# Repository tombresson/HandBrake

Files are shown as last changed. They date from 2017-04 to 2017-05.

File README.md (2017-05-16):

# USB Handbrake 

## Abstract

This goal of this project was to use a commercially available handbrake and convert it into a USB controller that could output an analog axis value, a joystick button (at a configurable threshold) or a keypress (at a configurable threshold).  The parts had to be readily available, but 3D printed parts could be utilized. The cost also had to be low, as this was a project for for a DIY piece of Sim Racing kit. Commercially available hardware already exists for a high (but not exuberant) price.

## Features

The USB Handbrake has the following features:

* Outputs a Joystick Analog (z-axis), Joystick Digital (button 1) or Keyboard key to provide universal support to any PC game
* Allows configuration of the device through the serial interface to configure:
  * Key that is pressed when in "Keyboard" mode
  * Threshold for the digital outputs
  * RGB LED Brightness
  * Deadzone for the "Pulled" and "Released" positions
* Allows for calibration of the device to set the full "Released" and "Pulled" sensor values
* Returns to the last mode after on power-up (Joystick Analog, Joystick Digital, or Keyboard)

## Hardware

### Mechanical

#### Bill of Materials

1 - Generic Generic Hydraulic Handbrake 
4 - M8 x 20mm x 1.25 (Box mounting and Rear O-ring attach point)
2 - M8 x 30mm x 1.25 (Front O-Ring attach point)
1 - M8 x 80mm x 1.25 ("Piston")
1 - 1/2" x 1/16" N52 Neodymium Magnet
1 - Spring (?)
2 - O-Rings (1-1/8 ID x 1-3/8 OD x 1/8 Diameter)
4 - Nylon Spacers
4 - M8 Washers
1 - 3D Printed Sensor Enclosure
1 - 3D Printed Bolt Guide Plate

#### Assembly

### Electronics

#### Bill of Materials

1 - Arduino platform (Teensy 3.1)
1 - Push Button
1 - RGB LED
1 - SOT-23 Breakout Board
1 - DRV5053RA (SOT-23 form factor)

#### Schematic

## Software

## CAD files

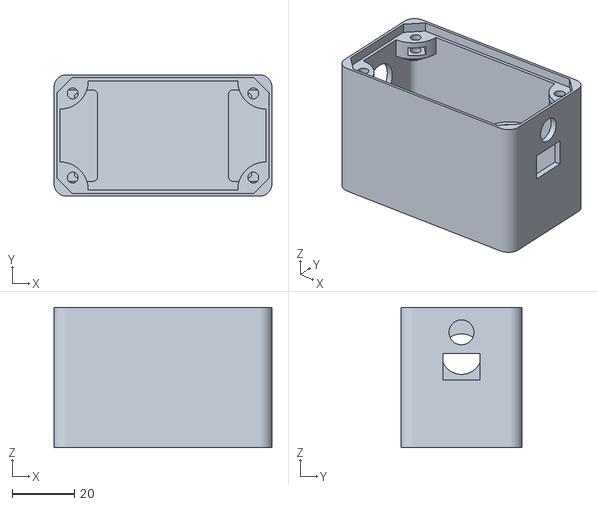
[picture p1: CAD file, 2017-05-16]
models/STLs/Electronics_Enclosure.stl
70.0 x 39.0 x 45.0

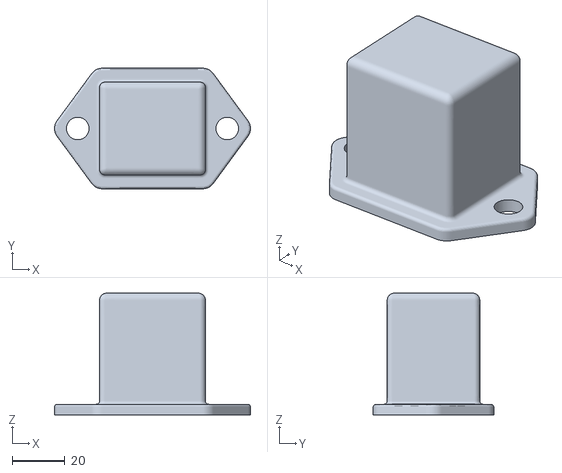
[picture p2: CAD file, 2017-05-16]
models/STLs/Sensor_Enclosure.stl
74.1 x 45.6 x 46.0

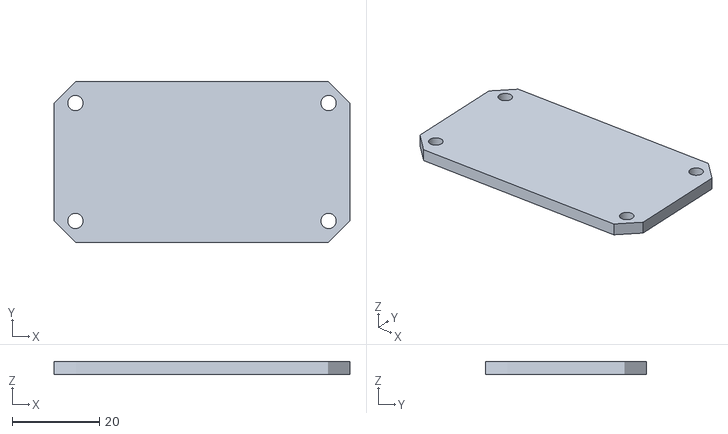
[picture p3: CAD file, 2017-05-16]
models/STLs/Electronics_Enclosure_Top.stl
67.8 x 36.8 x 3.00

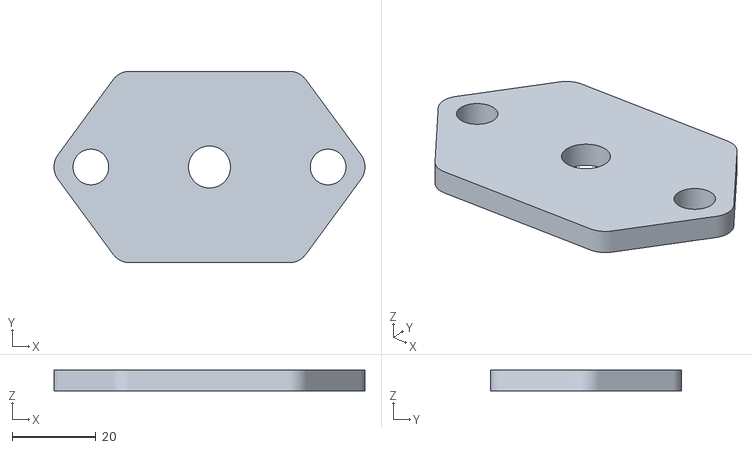
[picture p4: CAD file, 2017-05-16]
models/STLs/Bolt_Guide_Plate.stl
74.1 x 45.6 x 5.00

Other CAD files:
models/Fusion360/Bolt_Guide_Plate.f3d
models/Fusion360/Electronics_Enclosure.f3d
models/Fusion360/Electronics_Enclosure_Top.f3d
models/Fusion360/Sensor_Enclosure.f3d

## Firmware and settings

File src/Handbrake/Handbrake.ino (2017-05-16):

/* Complete USB Joystick Example
   Teensy becomes a USB joystick with 16 or 32 buttons and 6 axis input

   You must select Joystick from the "Tools > USB Type" menu

   Pushbuttons should be connected between the digital pins and ground.
   Potentiometers should be connected to analog inputs 0 to 5.

   This example code is in the public domain.
*/

/************************************* INCLUDES *************************************/

#include <stdint.h>

#include <EEPROMex.h>
#include <EEPROMVar.h>

#include "utilities.h"
#include "RGBTools.h"

/************************************** MACROS **************************************/
// Turns Debug on and off
#define HANDBRAKE_DEBUG 0

// Turn on verbose debugging
#define HANDBRAKE_DEBUG_VERBOSE 0

// EEPROM abstracted address position
#define HANDBRAKE_EEPROM_ADDR 0U

// Buffer for serial data
#define HANDBRAKE_SERIAL_BUFF_SIZE 64U

#define HANDBRAKE_ADC_MAX 1023U

#define HANDBRAKE_JOY_AXIS_MAX 1023U

// Button to send for the joystick button threshold
#define HANDBRAKE_JOY_BUTTON 1U

// Duration of button hold to enter calibration mode
#define HANDBRAKE_BUTTON_HOLD_TIME_MS 5000U

// Serial Config Parsing Timeout
#define HANDBRAKE_SERIAL_TIMEOUT 5000

// Resting value for joystick position
#define JOYSTICK_RESTING_POS 512U

#define HANDBRAKE_POSITION_MAX 100.0F
#define HANDBRAKE_POSITION_MIN 0.0F

// The hysteresis (in percentage) that in used for the button/key press
#define HANDBRAKE_THRESH_HYSTERESIS 5U

#define HANDBRAKE_LED_DEFAULT_BRIGHTNESS 100

#define HANDBRAKE_DEFAULT_BUTTON_THRESH 50U

// The percentage of the total range that the calibration is narrowed by
// This will ensure that the analog axis travels from 0 to 100%
// Upper deadband is for fully pulled back position, lower deadband is for released position
#define HANDBRAKE_UPPER_DEADZONE_BAND 5U
#define HANDBRAKE_LOWER_DEADZONE_BAND 10U

// GPIO pin for the mode select button
#define HANDBRAKE_MODE_SELECT_BUTTON 12

// Handbrake Modes
#define HANDBRAKE_UNKNOWN_MODE 0x00
#define HANDBRAKE_KEYBOARD_MODE 0x01
#define HANDBRAKE_BUTTON_MODE 0x02
#define HANDBRAKE_ANALOG_MODE 0x03
#define HANDBRAKE_CALIBRATE_MODE 0x04
#define HANDBRAKE_CONFIG_MODE 0x05

#define HANDBRAKE_NUM_MODES 0x06

/*********************************** DEFINITIONS ************************************/

const char *k_mode_names[HANDBRAKE_NUM_MODES] =
    {
        "UNKNOWN", //< Mode 0 is undefined
        "KEYBOARD",
        "BUTTON",
        "ANALOG",
        "CALIBRATION",
        "CONFIG"};

typedef struct
{
  uint32_t config_mode;
  uint32_t led_color;
  uint32_t blink_interval;
  uint8_t duty_cycle;
} configMode_t;

/// @brief Definition of the revision number for checking to see if EEPROM data is compatable
/// Anytime the EEPROM data structure is changed, this needs to be updated
#define REVISION_NUM 102

typedef struct
{
  uint32_t rev_number;            //< Revision number of the eeprom data struct
  uint32_t data_size;             //< Size of the data structure
  uint32_t cal_max;               //< Raw ADC value that represents 100%
  uint32_t cal_min;               //< Raw ADC value that represents 0%
  uint32_t button_threshold;      //< Threshold (0%-100%) where the button is activated/deactivated
  uint16_t conf_key_code;         //< Configured key for the Keyboard Mode
  uint8_t mode;                   //< Current mode the device is in
  uint8_t led_brightness;         //< The LED brightness for the LED indicator
  uint8_t upper_deadband_percent; //< The upper (pulled) deadband percentage
  uint8_t lower_deadband_percent; //< The lower (released) deadband percentage
} eepromData_t;

/******************************* FUNCTION DEFINITIONS *******************************/

static void handbrakeInitialConditions(void);
static void handbrakeProcessSerial(void);
static void handbrakeServiceModeButton(void);
static uint32_t handbrakeGetModeIdx(void);
static void handbrakeUpdateSettings(eepromData_t *p_data);
static void handbrakeLoadSettings(eepromData_t *p_data);
static bool handbrakeValidateSettings(const eepromData_t *p_data);
static uint32_t handbrakeProcessSerialLong(uint32_t upper_bound, uint32_t lower_bound, uint32_t original_value);
static uint16_t handbrakeProcessSerialFindKey(uint16_t original_key);
static uint32_t handbrakeFindKeyIdx(uint16_t key_code);

/************************************* GLOBALS **************************************/

// Array of modes which can be cycled through by momentary press on the button
static configMode_t modes[] =
    {
        {HANDBRAKE_KEYBOARD_MODE, Color::GREEN, 0, 0},
        {HANDBRAKE_BUTTON_MODE, Color::BLUE, 0, 0},
        {HANDBRAKE_ANALOG_MODE, Color::RED, 0, 0},
        {HANDBRAKE_CONFIG_MODE, Color::PURPLE, 1000, 90}};

// Configure the number of buttons.  Be careful not
// to use a pin for both a digital button and analog
// axis.  The pullup resistor will interfere with
// the analog voltage.
static const int numButtons = 8; // 16 for Teensy, 32 for Teensy++

static const char *gp_key_strings[] =
    {"A", "B", "C", "D", "E", "F", "G", "H", "I", "J",
     "K", "L", "M", "N", "O", "P", "Q", "R", "S", "T",
     "U", "V", "W", "X", "Y", "Z", "1", "2", "3", "4",
     "5", "6", "7", "8", "9", "0", "ENTER", "ESC", "BACKSPACE",
     "TAB", "SPACE", "MINUS", "EQUAL", "LEFT_BRACE", "RIGHT_BRACE",
     "BACKSLASH", "NON_US_NUM", "SEMICOLON", "QUOTE", "TILDE", "COMMA",
     "PERIOD", "SLASH", "CAPS_LOCK", "F1", "F2", "F3", "F4", "F5",
     "F6", "F7", "F8", "F9", "F10", "F11", "F12", "PRINTSCREEN",
     "SCROLL_LOCK", "PAUSE", "INSERT", "HOME", "PAGE_UP", "DELETE",
     "END", "PAGE_DOWN", "RIGHT", "LEFT", "DOWN", "UP", "NUM_LOCK",
     "KEYPAD_SLASH", "KEYPAD_ASTERIX", "KEYPAD_MINUS", "KEYPAD_PLUS", "KEYPAD_ENTER", "KEYPAD_1",
     "KEYPAD_2", "KEYPAD_3", "KEYPAD_4", "KEYPAD_5", "KEYPAD_6", "KEYPAD_7", "KEYPAD_8", "KEYPAD_9",
     "KEYPAD_0", "KEYPAD_PERIOD"};

static const uint16_t g_key_codes[] =
    {KEY_A, KEY_B, KEY_C, KEY_D, KEY_E, KEY_F, KEY_G, KEY_H, KEY_I, KEY_J,
     KEY_K, KEY_L, KEY_M, KEY_N, KEY_O, KEY_P, KEY_Q, KEY_R, KEY_S, KEY_T,
     KEY_U, KEY_V, KEY_W, KEY_X, KEY_Y, KEY_Z, KEY_1, KEY_2, KEY_3, KEY_4,
     KEY_5, KEY_6, KEY_7, KEY_8, KEY_9, KEY_0, KEY_ENTER, KEY_ESC, KEY_BACKSPACE,
     KEY_TAB, KEY_SPACE, KEY_MINUS, KEY_EQUAL, KEY_LEFT_BRACE, KEY_RIGHT_BRACE,
     KEY_BACKSLASH, KEY_NON_US_NUM, KEY_SEMICOLON, KEY_QUOTE, KEY_TILDE, KEY_COMMA,
     KEY_PERIOD, KEY_SLASH, KEY_CAPS_LOCK, KEY_F1, KEY_F2, KEY_F3, KEY_F4, KEY_F5,
     KEY_F6, KEY_F7, KEY_F8, KEY_F9, KEY_F10, KEY_F11, KEY_F12, KEY_PRINTSCREEN,
     KEY_SCROLL_LOCK, KEY_PAUSE, KEY_INSERT, KEY_HOME, KEY_PAGE_UP, KEY_DELETE,
     KEY_END, KEY_PAGE_DOWN, KEY_RIGHT, KEY_LEFT, KEY_DOWN, KEY_UP, KEY_NUM_LOCK,
     KEYPAD_SLASH, KEYPAD_ASTERIX, KEYPAD_MINUS, KEYPAD_PLUS, KEYPAD_ENTER, KEYPAD_1,
     KEYPAD_2, KEYPAD_3, KEYPAD_4, KEYPAD_5, KEYPAD_6, KEYPAD_7, KEYPAD_8, KEYPAD_9,
     KEYPAD_0, KEYPAD_PERIOD};

// Get the count of the elements in the array
static const uint32_t k_button_array_cnt = COUNT_OF(gp_key_strings);

// Holds the last selected mode
static uint8_t g_last_mode = 0U;

// Serial buffer, for processing serial data
static uint8_t g_serial_buff[HANDBRAKE_SERIAL_BUFF_SIZE];

static uint16_t g_cal_data_min = UINT16_MAX;
static uint16_t g_cal_data_max = 0U;

// initialize a common cathode LED
RGBTools rgb(RGB_R_PIN, RGB_G_PIN, RGB_B_PIN);

static eepromData_t g_saved_data;

static const eepromData_t k_default_save_data =
    {
        .rev_number = REVISION_NUM,
        .data_size = sizeof(eepromData_t),
        .cal_max = 0U,
        .cal_min = 0U,
        .button_threshold = HANDBRAKE_DEFAULT_BUTTON_THRESH,
        .conf_key_code = 24U, //< Index of KEY_X
        .mode = HANDBRAKE_ANALOG_MODE,
        .led_brightness = HANDBRAKE_LED_DEFAULT_BRIGHTNESS,
        .upper_deadband_percent = HANDBRAKE_UPPER_DEADZONE_BAND,
        .lower_deadband_percent = HANDBRAKE_LOWER_DEADZONE_BAND,
};

// ********** INPUT CONFIG ************/
// Mode switch button input pin
static const uint32_t config_button_pin = 6U;

static const uint32_t hall_analog_pin = 0U;

/**************************************  CODE ****************************************/

/**
 * @brief Initializes the Handbrake controller. Standard Arduino setup function.
 */
void setup(void)
{
  // Set LED color
  rgb.setColor(Color::OFF);

  // Setup config pins
  pinMode(config_button_pin, INPUT_PULLUP);

  // you can print to the serial monitor while the joystick is active!
  Serial.begin(9600);

  // Set serial parsing timeout
  Serial.setTimeout(HANDBRAKE_SERIAL_TIMEOUT);

  // configure the joystick to manual send mode.  This gives precise
  // control over when the computer receives updates, but it does
  // require you to manually call Joystick.send_now().
  Joystick.useManualSend(true);

  /** @todo: Set pin mode for each button needed, not in bulk.
    * for (int i = 0; i < numButtons; i++) {
    *   pinMode(i, INPUT_PULLUP);
    * }
    */

  // Set initial joystick conditions
  handbrakeInitialConditions();

#if HANDBRAKE_DEBUG
  delay(2500);
  Serial.println("\f*** USB Handbrake Initialized! ***");
#endif

  // Limit the number of EEPROM write to 200, in-case something gets
  // messed up. This will keep the EEPROM cell from getting worn out prematurely
  // The side-effect from hitting the limit during normal use would be any 
  // changes made to the EEPROM data after 200 writes would not be saved. 
  EEPROM.setMaxAllowedWrites(200U);

  // Load EEPROM data into global structure
  handbrakeLoadSettings(&g_saved_data);
  bool settings_result = handbrakeValidateSettings(&g_saved_data);

  // Default some settings if the settings are not valid
  if (!settings_result)
  {
    // Default the deadbands
    g_saved_data.upper_deadband_percent = HANDBRAKE_UPPER_DEADZONE_BAND;
    g_saved_data.lower_deadband_percent = HANDBRAKE_LOWER_DEADZONE_BAND;
  }

  // If mode is undefined, load analog mode
  if ((g_saved_data.mode == 0U) ||
      (g_saved_data.mode > (HANDBRAKE_NUM_MODES - 1U)))
  {
    g_saved_data.mode = HANDBRAKE_ANALOG_MODE;
  }

  // Keep LED from being completely off
  if (g_saved_data.led_brightness == 0U)
  {
    g_saved_data.led_brightness = HANDBRAKE_LED_DEFAULT_BRIGHTNESS;
  }

  // Update last mode to the current mode
  g_last_mode = g_saved_data.mode;

  // if eeprom doesn't contain valid data, write it now
  if (!settings_result)
  {
    handbrakeUpdateSettings(&g_saved_data);
  }

  // Set the LED color for the current mode
  uint32_t mode_idx = handbrakeGetModeIdx();
  rgb.setColor(modes[mode_idx].led_color, g_saved_data.led_brightness);
}

/**
 * @brief Main loop for the Handbrake controller. Standard Arduino loop function.
 */
void loop(void)
{

  // Holds the mode for the last loop cycle
  static uint8_t previous_mode = 0U;

  // Always Read hall sensor
  uint16_t data = analogRead(hall_analog_pin);

  // Normal operating modes
  if ((g_saved_data.mode == HANDBRAKE_KEYBOARD_MODE) ||
      (g_saved_data.mode == HANDBRAKE_ANALOG_MODE) ||
      (g_saved_data.mode == HANDBRAKE_BUTTON_MODE))
  {
    //Apply calibration transform to the data
    float divisior = (g_saved_data.cal_max - g_saved_data.cal_min);
    float position = HANDBRAKE_POSITION_MIN;

    // Calculate position (0.0F - 100.0F)
    // Avoid div by 0
    if (divisior > HANDBRAKE_POSITION_MIN)
    {
      // limit data from going below the calibrated min value
      // but don't modify the incoming data
      uint16_t adjusted_data = max(data, g_saved_data.cal_min);

      // Calculate position
      position = ((float)(adjusted_data - g_saved_data.cal_min) / divisior) * HANDBRAKE_POSITION_MAX;
    }

    // Limit position
    if (position < HANDBRAKE_POSITION_MIN)
    {
      position = HANDBRAKE_POSITION_MIN;
    }
    else if (position > HANDBRAKE_POSITION_MAX)
    {
      position = HANDBRAKE_POSITION_MAX;
    }
    else
    {
      // Don't modify the value
    }

// Report calculated position
#if HANDBRAKE_DEBUG_VERBOSE
    Serial.print("data: ");
    Serial.print(data);
    Serial.print(" | position: ");
    Serial.println(position);
#endif

    if (g_saved_data.mode == HANDBRAKE_ANALOG_MODE)
    {
      // set the Z axis position to data
      Joystick.Z((position / HANDBRAKE_POSITION_MAX) * HANDBRAKE_JOY_AXIS_MAX);
      Joystick.send_now();
    }
    else if (g_saved_data.mode == HANDBRAKE_BUTTON_MODE)
    {
      // Set the button if above the threshold
      if (position >= (float)g_saved_data.button_threshold)
      {
        Joystick.button(HANDBRAKE_JOY_BUTTON, true);
      }
      // Release the button if below the threshold with the hysteresis or if
      // position happens to become 0
      else if ((position < (float)(g_saved_data.button_threshold - HANDBRAKE_THRESH_HYSTERESIS)) ||
               (position == 0.0f))
      {
        Joystick.button(HANDBRAKE_JOY_BUTTON, false);
      }
      else
      {
        // Do nothing
      }
      Joystick.send_now();
    }
    else if (g_saved_data.mode == HANDBRAKE_KEYBOARD_MODE)
    {
      // Set keypress if above the threshold
      if (position >= (float)g_saved_data.button_threshold)
      {
        Keyboard.set_key1(g_saved_data.conf_key_code);
      }
      // Release the button if below the threshold with the hysteresis or if
      // position happens to become 0
      else if ((position < (float)(g_saved_data.button_threshold - HANDBRAKE_THRESH_HYSTERESIS)) ||
               (position == 0.0f))
      {
        Keyboard.set_key1(0);
      }
      else
      {
        // Do nothing
      }
      Keyboard.send_now();
    }
  }
  else if (g_saved_data.mode == HANDBRAKE_CONFIG_MODE)
  {
    // Do Configuration
    // Process serial commands
    if (Serial.available() > 0)
    {
      handbrakeProcessSerial();
    }
  }
  else if (g_saved_data.mode == HANDBRAKE_CALIBRATE_MODE)
  {
    // Do calibration
    // Find limits for calibration
    g_cal_data_min = min(data, g_cal_data_min);
    g_cal_data_max = max(data, g_cal_data_max);
  }
  else
  {
#if HANDBRAKE_DEBUG
    Serial.println("Mode changed to: UNKNOWN");
#endif
    assert(false);
  }

  // Service the config button and mode changes
  handbrakeServiceModeButton();

  // Process events upon state changes
  // Holds the mode for the last loop cycles from mode changes
  if (previous_mode != g_saved_data.mode)
  {
    // Store the previously selected mode into last mode, so we can return if needed
    g_last_mode = previous_mode;

// Print out the mode change info
#if HANDBRAKE_DEBUG
    // Holds the mode for the last loop cycleG
    assert((previous_mode < HANDBRAKE_NUM_MODES) && (g_saved_data.mode < HANDBRAKE_NUM_MODES));
    Serial.print("Mode changed: ");
    // Holds the mode for the last loop cycle
    Serial.print(k_mode_names[previous_mode]);
    Serial.print(" -> ");
    Serial.println(k_mode_names[g_saved_data.mode]);
#endif

    // If current mode is normal operating mode, save to eeprom
    if ((g_saved_data.mode == HANDBRAKE_KEYBOARD_MODE) ||
        (g_saved_data.mode == HANDBRAKE_BUTTON_MODE) ||
        (g_saved_data.mode == HANDBRAKE_ANALOG_MODE))
    {
      handbrakeUpdateSettings(&g_saved_data);
    }

    // HANDLE EVENTS FOR ENTERING MODE
    if (g_saved_data.mode == HANDBRAKE_CONFIG_MODE)
    {
      printConfigMenu();
    }
    else if (g_saved_data.mode == HANDBRAKE_CALIBRATE_MODE)
    {
      // Change LED for Calibrate mode special case
      rgb.setColor(Color::WHITE);
      rgb.blinkEnable(500, 50);

      // Reset min and max
      g_cal_data_min = UINT16_MAX;
      g_cal_data_max = 0U;
    }
    else
    {
      // Do nothing...
    }

    // HANDLE EVENT FOR LEAVING MODE
    // Holds the mode for the last loop cycle
    if (previous_mode == HANDBRAKE_CALIBRATE_MODE)
    {
      // Calculate the deadband
      uint32_t upper_deadband = (uint32_t)((float)(g_cal_data_max - g_cal_data_min) *
                                           ((float)g_saved_data.upper_deadband_percent / 100.0f));
      uint32_t lower_deadband = (uint32_t)((float)(g_cal_data_max - g_cal_data_min) *
                                           ((float)g_saved_data.lower_deadband_percent / 100.0f));

      // Calibration mode has been exited, store new calibration values
      // narrowed by the deadband value
      g_saved_data.cal_max = g_cal_data_max - upper_deadband;
      g_saved_data.cal_min = g_cal_data_min + lower_deadband;

#if HANDBRAKE_DEBUG
      Serial.print("Raw Calibration (no deadband) (min,max): ");
      Serial.print(g_cal_data_min);
      Serial.print(",");
      Serial.println(g_cal_data_max);
      Serial.print("New Calibration (min,max): ");
      Serial.print(g_saved_data.cal_min);
      Serial.print(",");
      Serial.println(g_saved_data.cal_max);
#endif

      // Save the data to eeprom
      handbrakeUpdateSettings(&g_saved_data);
    }

    // Reset controller on mode change
    handbrakeInitialConditions();
  }

  // Service the LED
  rgb.serviceLED();

  // Set previous mode
  // Holds the mode for the last loop cycleus mode to current mode
  previous_mode = g_saved_data.mode;

  // a brief delay, so this runs "only" 200 times per second
  delay(5);
}

/**
 * @brief Processes and handles data coming in from the Serial interface. This is for advanced
 * configuration functions and debugging.
 */
static void handbrakeProcessSerial(void)
{
  // Process Recognized commands
  uint8_t byte = Serial.read();
  if (byte == '1') // Key Binding
  {
    Serial.print("\r\nList of Usable Keys:\r\n\r\n");
    uint32_t key_idx;
    for (key_idx = 0U; key_idx < k_button_array_cnt; key_idx++)
    {
      Serial.printf("%s", gp_key_strings[key_idx]);
      if (key_idx < (k_button_array_cnt - 1))
      {
        Serial.print(", ");
      }
    }

    Serial.print("Please type the name of the key to bind and press ENTER: ");
    uint16_t new_key = handbrakeProcessSerialFindKey(g_saved_data.conf_key_code);
    uint32_t new_key_idx = handbrakeFindKeyIdx(new_key);
    if(new_key_idx < k_button_array_cnt)
    {
      g_saved_data.conf_key_code = new_key;
      Serial.printf("\r\nKey set to: %s\r\n", gp_key_strings[new_key_idx]);
    }
    else
    {
      Serial.printf("Failed to set key to index %d.", new_key_idx);
    }
  }
  else if (byte == '2') // Button Threshold
  {
    // @todo: When developed, the button threshold should be a 0-100% value of the calibrated range
    Serial.print("Enter a new button threshold value (5 to 95)");
    Serial.printf(" (Current:%d/Default:%d): ", g_saved_data.button_threshold, HANDBRAKE_DEFAULT_BUTTON_THRESH);
    g_saved_data.button_threshold = handbrakeProcessSerialLong(95U, 5U, g_saved_data.button_threshold);
    Serial.printf("\r\nValue set to: %d\r\n", g_saved_data.button_threshold);
  }
  else if (byte == '3') // LED Brightness
  {
    Serial.print("Enter a new brightness value (1 to 255)");
    Serial.printf(" (Current:%d/Default:%d): ", g_saved_data.led_brightness, HANDBRAKE_LED_DEFAULT_BRIGHTNESS);
    g_saved_data.led_brightness = handbrakeProcessSerialLong(255U, 1U, g_saved_data.led_brightness);
    Serial.printf("\r\nValue set to: %d\r\n", g_saved_data.led_brightness);
  }
  else if (byte == '4') // Upper (Pulled) Deadband
  {
    Serial.print("Enter a new upper deadband value (0 to 100)");
    Serial.printf(" (Current:%d/Default:%d): ", g_saved_data.upper_deadband_percent, HANDBRAKE_UPPER_DEADZONE_BAND);
    g_saved_data.upper_deadband_percent = handbrakeProcessSerialLong(100, 0U, g_saved_data.upper_deadband_percent);
    Serial.printf("\r\nValue set to: %d\r\n", g_saved_data.upper_deadband_percent);
  }
  else if (byte == '5') // Lower (Released) Deadband
  {
    Serial.print("Enter a new lower deadband value (0 to 100)");
    Serial.printf(" (Current:%d/Default:%d): ", g_saved_data.lower_deadband_percent, HANDBRAKE_LOWER_DEADZONE_BAND);
    g_saved_data.lower_deadband_percent = handbrakeProcessSerialLong(100, 0U, g_saved_data.lower_deadband_percent);
    Serial.printf("\r\nValue set to: %d\r\n", g_saved_data.lower_deadband_percent);
  }
  else if ((byte == 'D') || (byte == 'd')) //Reset Defaults
  {
    // Reset all of the save data, this could be changed to be more targeted of a reset
    // but at the frequency of the use this function should see, it doesn't seem worth it.
    g_saved_data = k_default_save_data;
    // Save the defaults
    handbrakeUpdateSettings(&g_saved_data);
    // Restore mode back to config so we don't leave this mode
    g_saved_data.mode = HANDBRAKE_CONFIG_MODE;
    Serial.print("All values restored to default. Please calibrate handbrake again.\r\n");
  }
  else
  {
    printConfigMenu();
  }
}

static uint16_t handbrakeProcessSerialFindKey(uint16_t original_key)
{
  bool match_found = false;
  uint32_t key_idx = 0;
  uint32_t num_bytes = serialReadBytes(&g_serial_buff[0U], HANDBRAKE_SERIAL_BUFF_SIZE, 5000U);
  if (num_bytes > 0)
  {
    // Make sure buffer is null terminated
    g_serial_buff[HANDBRAKE_SERIAL_BUFF_SIZE - 1] = '\0';

    // Convert all lower case to upper case
    uint32_t idx;
    for(idx = 0U; idx < HANDBRAKE_SERIAL_BUFF_SIZE; idx++)
    {
      uint8_t c = g_serial_buff[idx];
      g_serial_buff[idx] = ((c <= 'z' && c >= 'a') ? c - 32 : c);
    }

    // Find the index of the string that was typed
    while((key_idx < k_button_array_cnt) && !match_found)
    {
      int32_t result = strcmp(gp_key_strings[key_idx], (const char *)g_serial_buff);
      if(result == 0)
      {
        match_found = true;
      }
      else
      {
        key_idx++;
      }
    }
  }

  // Either return the match or the original key
  return ((match_found) ? g_key_codes[key_idx] : original_key );

}
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

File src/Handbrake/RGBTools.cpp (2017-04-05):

/**
   @class RGBTools

   @brief Use this code with RGB-LEDs

   @detail This class implements methods to control a RGB LED with Arduino
*/

#include "RGBTools.h"

/**
   constructor; saves the pins

   @param[in] r The Arduino pin number of the red pin of the LED
   @param[in] g The Arduino pin number of the green pin of the LED
   @param[in] b The Arduino pin number of the blue pin of the LED
*/
RGBTools::RGBTools(uint8_t r, uint8_t g, uint8_t b) {
  this->r_pin = r;
  this->g_pin = g;
  this->b_pin = b;

  pinMode(r, OUTPUT);
  pinMode(g, OUTPUT);
  pinMode(b, OUTPUT);
}

/**
   Constructor using the Mode enum in header file.
   Ex: RGBTools(9, 10, 11, COMMON_ANODE);

   @param[in] r The Arduino pin number of the red pin of the LED
   @param[in] g The Arduino pin number of the green pin of the LED
   @param[in] b The Arduino pin number of the blue pin of the LED
   @param[in] mode The mode of the RGB (common cathode / common anode)
*/
RGBTools::RGBTools(uint8_t r, uint8_t g, uint8_t b, Mode mode) {
  this->r_pin = r;
  this->g_pin = g;
  this->b_pin = b;

  this->mode = mode;
}

/**
   Set LED-color to custom color instantly

   @param[in] r The red value ([0-255])
   @param[in] g The green value ([0-255])
   @param[in] b The blue value ([0-255])
*/
void RGBTools::setColor(uint8_t r, uint8_t g, uint8_t b)
{
  setColor(r,g,b,255);  
}

/**
   Set LED-color to custom color instantly

   @param[in] r The red value ([0-255])
   @param[in] g The green value ([0-255])
   @param[in] b The blue value ([0-255])
   @param[in] brightness The overall brightness ([0-255])
*/
void RGBTools::setColor(uint8_t r, uint8_t g, uint8_t b,  uint8_t brightness) {

  // Apply the brightness modifier
  r = ((255 - brightness) > r) ? 0U : (r - (255 - brightness));
  b = ((255 - brightness) > b) ? 0U : (b - (255 - brightness));
  g = ((255 - brightness) > g) ? 0U : (g - (255 - brightness));

  // set color of LED
  if (mode == COMMON_CATHODE)
  {
    analogWrite(r_pin, r);
    analogWrite(g_pin, g);
    analogWrite(b_pin, b);
  }
  else
  {
    analogWrite(r_pin, 256 - r);
    analogWrite(g_pin, 256 - g);
    analogWrite(b_pin, 256 - b);
  }

  // set color and save state if color indicates not off
  if ((r != 0U) || (b != 0U) || (g != 0U))
  {
    this->curr_r = r;
    this->curr_g = g;
    this->curr_b = b;
  }
}

/**
   Set LED-color to custom color instantly Uses a 32 bit value to set a color.

   @param[in] color The 32 bit color value (eg. 0xFF0000 for red)
*/
void RGBTools::setColor(uint32_t color) {
  uint8_t red =   (uint8_t)   ((color & 0xFF0000) >> 16);
  uint8_t green = (uint8_t)   ((color & 0x00FF00) >> 8);
  uint8_t blue = (uint8_t)     (color & 0x0000FF);
  setColor(red, green, blue, 255);
}

/**
   Set LED-color to custom color instantly Uses a 32 bit value to set a color.

   @param[in] color The 32 bit color value (eg. 0xFF0000 for red)
   @param[in] brightness The overall brightness ([0-255])
*/
void RGBTools::setColor(uint32_t color, uint8_t brightness) {
  uint8_t red =   (uint8_t)   ((color & 0xFF0000) >> 16);
  uint8_t green = (uint8_t)   ((color & 0x00FF00) >> 8);
  uint8_t blue = (uint8_t)     (color & 0x0000FF);
  setColor(red, green, blue, brightness);
}

/**
   Fades to custom color in specific time in specific steps

   @param[in] r The red value ([0-255])
   @param[in] g The green value ([0-255])
   @param[in] b The blue value ([0-255])
   @param[in] steps The number of steps to use
   @param[in] duration The duration of the fading in ms
*/
void RGBTools::fadeTo(uint8_t r, uint8_t g, uint8_t b, int steps, int duration) {
  // calculate difference to target
  uint8_t diff_r = r - curr_r;
  uint8_t diff_g = g - curr_g;
  uint8_t diff_b = b - curr_b;

  // calculate the width of each step multiplied by 100 as to not lose decimal data
  int steps_r = (diff_r * 100 / steps);
  int steps_g = (diff_g * 100 / steps);
  int steps_b = (diff_b * 100 / steps);

  // calculate delay between steps
  int delay_value = (duration / steps);

  // loop through the steps (i: distance to target)
  for (int i = steps - 1; i >= 0; i--) {

    // set color of current step
    this->setColor(
      r - (i * steps_r) / 100,	// red target minus distance to target steps (divided by 100 as to offset steps_r calculations)
      g - (i * steps_g) / 100,	// green
      b - (i * steps_b) / 100 	// blue
    );

    // delay until next step
    delay((unsigned long) delay_value);
  }
}

/**
   @brief Enables blinking with a specific duty cycle and rate
   @param[in] blink_rate The rate, in ms, in which the LED will blink
   @param[in] duty_cycle The duty cycle (0-100) of the blinking. 0 will be
   completly off, and 100 will be completely on.
*/
void RGBTools::blinkEnable(uint32_t rate, uint8_t duty_cycle)
{
  // Only blink if the rate is greater than zero
  if(rate > 0U)
  {
    if (duty_cycle == 100U)
    {
      // Disable blinking
      this->blink_enabled = false;

      // turn LED back on fully
      this->setColor(this->curr_r, this->curr_g, this->curr_b);

      // Reset LED state
      this->blink_led_state = true;
    }
    else if ( duty_cycle == 0U)
    {
      this->setColor(Color::OFF);
    }
    else
    {
      this->blink_rate_ms = rate;

      // limit duty cycle to 100
      this->blink_duty_cycle = min(duty_cycle, 100);

      this->blink_enabled = true;
      this->blink_led_state = true;
    }
  }
  else
  {
    blinkDisable();
  }
}

void RGBTools::blinkDisable(void)
{
  // Disable blinking
  this->blink_enabled = false;

  // turn LED back on fully
  this->setColor(this->curr_r, this->curr_g, this->curr_b);

  // Reset LED state
  this->blink_led_state = true;
}

void RGBTools::serviceBlink(void)
{
  // check to see if it's time to blink the LED; that is, if the
  // difference between the current time and last time you blinked
  // the LED is bigger than the interval at which you want to
  // blink the LED.

  unsigned long currentMillis = millis();

  uint32_t on_time  = (uint32_t)((float)this->blink_rate_ms *
                                 ((float)this->blink_duty_cycle / 100.0F));
  uint32_t off_time = (uint32_t)((float)this->blink_rate_ms *
                                 ((100.0F - (float)this->blink_duty_cycle) / 100.0F));

  if (((currentMillis - this->last_blink_time) >= on_time) && this->blink_led_state)
  {
    // save the last time you blinked the LED
    this->last_blink_time = currentMillis;

    // Change the LED state
    this->setColor(Color::OFF);
    this->blink_led_state = false;
  }
  else if (((currentMillis - this->last_blink_time) >= off_time) && !(this->blink_led_state))
  {
    // save the last time you blinked the LED
    this->last_blink_time = currentMillis;

    // Change the LED state
    this->setColor(this->curr_r, this->curr_g, this->curr_b);
    this->blink_led_state = true;
  }
  else
  {
    // Do nothing...
  }
}
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

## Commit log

2017-01-26 Move LED init earlier in program
    This avoids the LED being lit for a period of time at bootup
    [Handbrake.ino]
2017-01-26 Add ability to do button handling
2017-02-01 Scale the incoming data based on calibration
2017-02-02 Many small changes, see below
    - Fix coding errors for compilation
    - Declare eeprom data variable for use
    - Prevent divide by zero for position calculation
    - Add debug data for analog hall pin
    [Handbrake.ino]
2017-02-08 Add controller reset capability to runtime
    [Handbrake.ino]
2017-04-04 Add hysteresis to the button/key press
2017-04-04 No longer modify the raw data when limiting the data for position calculation
    [Handbrake.ino]
2017-04-05 Add ability to change brightness to LED library
    This is done through modifying the PWM value across all the LED channels uniformly.
    It may however cause issues with certain colors.
    [RGBTools.cpp]
2017-04-05 Many new features
    New features include:
    * Retooled serial config menu
    * LED brightness configuration option
    * Upper/Lower deadband configuration
    * Additional checking of the EEPROM data structure
    Also some prep for the keybind feature
2017-04-05 Add missing paren from serial print
    [Handbrake.ino]
2017-04-07 Fix bug related to keyboard not sending keys
    Forgot the send command. Derp.
    [Handbrake.ino]
2017-04-07 Missed this change related to whitespace
    Must have commited the removal and missed the addition or something...
    [Handbrake.ino]
2017-05-16 Add 3D Models and STLs
    [Bolt_Guide_Plate.f3d, Bolt_Guide_Plate.stl, Electronics_Enclosure.f3d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]
2017-05-16 Move handbrake source and add EEPROM write limit
    Limiting the EEPROM writes per power-cycle will keep a bug in the source code from unnecessarily burning up EEPROM write cycles
    [Handbrake.ino]
2017-05-16 Include Teensy precompiled binary
